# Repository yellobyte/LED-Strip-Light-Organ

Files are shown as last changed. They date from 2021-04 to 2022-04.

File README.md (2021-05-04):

# 3-Channel LED-Strip Light Organ with Arduino Nano #

A light (or color) organ is an electronic device which converts an audio signal into rhythmic light effects. Invented in the 70's they are still popular in discotheques and party rooms though.
Now that **LED Strips** became fairly cheap they can replace normal light bulbs used in the earlier years and make the color organ look more modern.

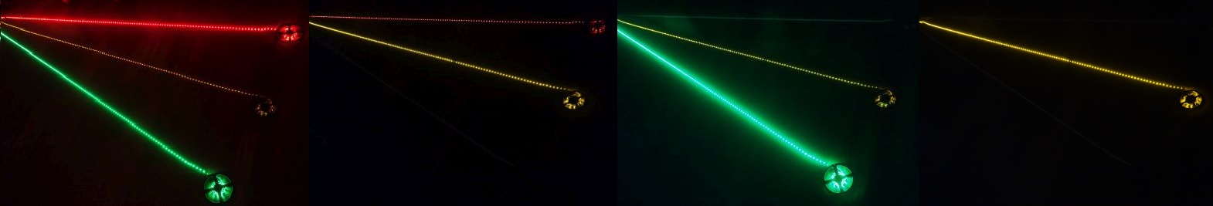
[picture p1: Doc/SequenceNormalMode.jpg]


The electronic circuit of a normal light organ separates the audio signal into several frequency bands and dimms the light bulbs or LEDs according to the average level of each band.

For a decent visual impression at least 3 bands (channels) are needed: low frequencies (bass), middle frequencies and high frequencies (treble). For best visual results each channel should control a light source of different color, e.g bass = red, middle = yellow and treble = green.

## Technical Infos ##

We have 3 channels and therefore control 3 LED Strips. Their specified working voltage must be 12V DC. The maximum length of the LED Strips the device can handle is mainly determined by the current consumption (amperes per meter length) of each LED Strip and the maximum current rating of the external 12V power supply used.

To give you a real world example: The external power supply I tested the device with was a MeanWell GS90A12 with a maximum current rating of 6.7A DC. Therefore I set the overcurrent limit to 2.2A per channel (the device itself doesn't need much). That limit allowed me to use LED Strips of 5m length with 60 LEDs (Type 3528 SMD in red, yellow or green) per meter. The overcurrent protection circuitry never got triggered.

The light organ has 3 working modes: [Normal](https://github.com/yellobyte/LED-Strip-Light-Organ/blob/main/Doc/NormalMode.mp4), [Rhythm](https://github.com/yellobyte/LED-Strip-Light-Organ/blob/main/Doc/RhythmMode.mp4) and [Cyclic](https://github.com/yellobyte/LED-Strip-Light-Organ/blob/main/Doc/Cyclic.mp4), which can be selected by pressing the **mode selection** button. 

An Arduino Nano 328P continuously samples all 3 filter outputs und transforms their voltage levels into digital PWM signals which feed the output stages with their IRF540N Power MOSFETs. Overtemperature & overcurrent protection (overload OL protection) has been integrated. 

The electrical circuit had to be devided into 2 separate [PCBs](https://github.com/yellobyte/LED-Strip-Light-Organ/blob/main/Doc/BoardTop.JPG), a **Filter-PCB** and a **Power-PCB** as I only call the basic version of the Eagle Design Tool my own and PCB size is limited to Eurocard size. But this proved to be very fortunate in the end for I redesigned the output stages a few times but didn't have to redo the analog stages. Please have a look at folder [**EagleFiles**](https://github.com/yellobyte/LED-Strip-Light-Organ/blob/main/EagleFiles) for schematic & PCB details.

The block diagram of the light organ is as follows:

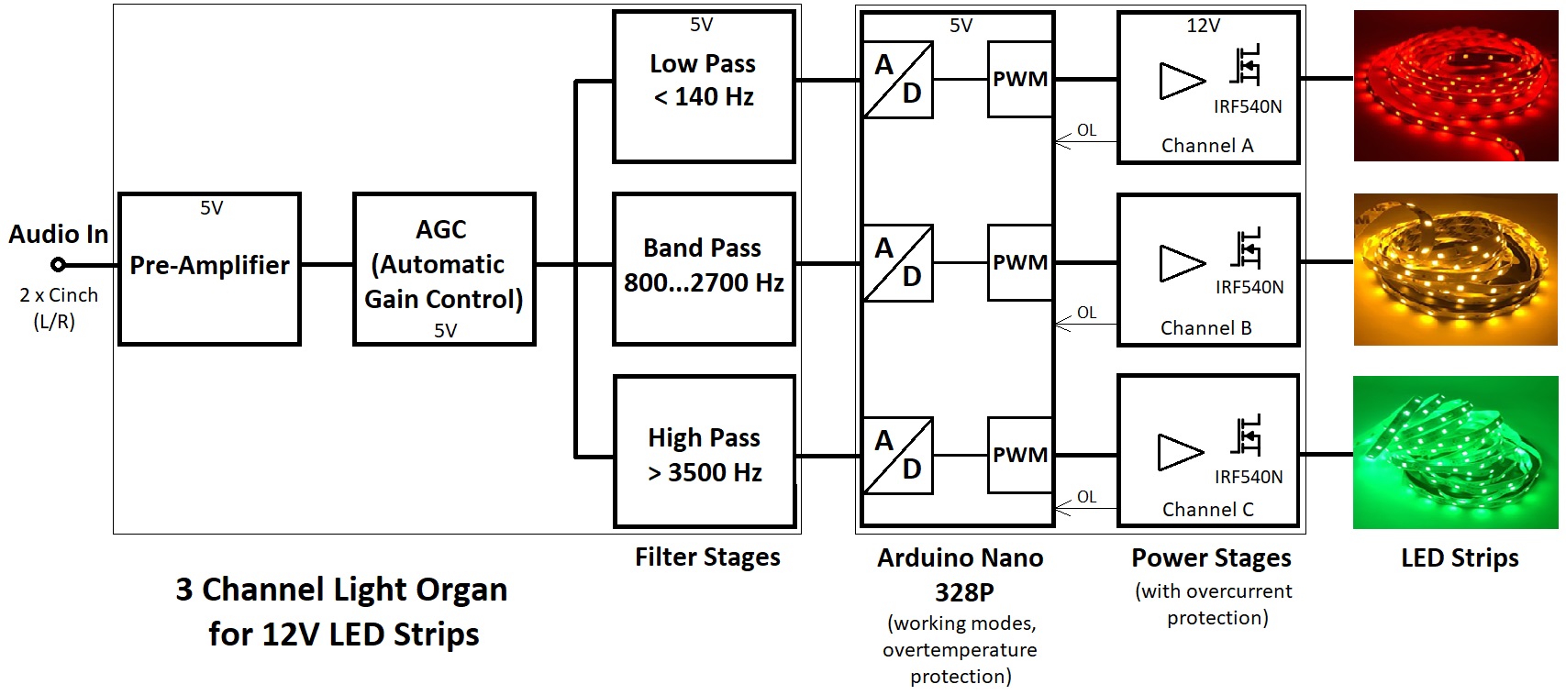
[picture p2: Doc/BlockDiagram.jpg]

   
### The Filter-PCB: ###

The MC33078 Op amps in the pre-amplifier and AGC stages proved perfect for the task. They might be substituted with cheaper Op amps, e.g. TL082, TLC277 or MC1458 but this comes with a loss of signal quality (distortion!). Especially the MC1458 wasn't able to pull the signal fully down to the lower rail and the TLC277 showed some crossover distortion.

The cheap LM358 Op amps used in the 3 filter stages generate crossover distortion as well but this is of no consequence in that particular application.

The AGC stage is simple but very effective and produces hardly any distortion even with high input signals applied. This stage is needed in order to normalize the signal level fed into the filter stages as the signal level from the many audio sources can vary by an order of magnitude (MP3/CD/Vinyl player, FM or internet radio, etc.).

Each of the 3 filter circuits uses an Op amp and some passive components (Rs/Cs). The resistors with strange values (6k16, 14k7, 16k9, 23k7, 71k5) belong to the E48 (2%) or E96 (1%) series. The filter circuits (2nd order) were calculated with the help of **FilterLab** from Microchip. It's available at no cost, easy to use and very intuitive. 

LED1 to LED6 have been added mainly for testing purposes. They come handy when you don't have any LED-Strips available but still want to do some tests on the device. They too are PWM controlled and show the exact same visual effects as the LED-Strips would.

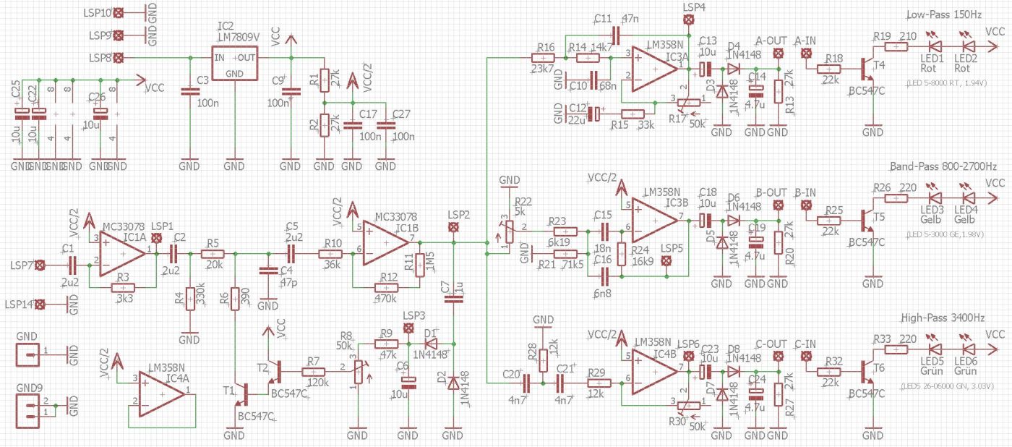
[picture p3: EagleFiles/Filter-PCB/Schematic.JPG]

     
### The Power-PCB: ###

The Arduino Nano 328P module is an ideal device for sampling the three filter outputs and generating PWM signals needed by the power stages. It only runs on 16MHz but this proved fast enough for the task.

The code running on the Arduino Nano is available in folder [Software](https://github.com/yellobyte/LED-Strip-Light-Organ/blob/main/Software). It was generated with VSCode/PlatformIO.

The Power MOSFETs IRF540N work as High-Side Switches (in "common drain" configuration) and need a gate voltage higher than the Nano can provide in this application, thats why 12V DC-DC converters (I/O isolated -> output side floating) had to be used. The reason is that the source voltage of the MOSFETs approaches the +12V supply voltage when switched on. To keep the MOSFETs turned on the IR2125 outputs must drive the MOSFETs gate voltage 10-12V higher than the supply voltage.

Shunt resistors (R6/R12/R18 - 0.15Ohm/2W/5%/Wire) sit between the MOSFETs and the output sockets in order to measure the output current and utilize the current sense input of the MOSFET drivers IR2125. When the IR2125 detects overcurrent it shuts down immediately until the next PWM impuls. The software in the Arduino Nano detects this condition and shuts down the affected channel even longer (5 sec) before releasing it again. No harm is done at all in case you have a permanent short on the output lines, provided you properly calibrated the trigger point of course!

The power stages by design could deliver 3-4 amperes per channel without problems. In practice the limiting factor probably will be the external 12V DC power supply. The driver MOSFETs IRF540N (Idmax > 20A) operate way from their absolute maximum ratings and only get handwarm in the enclosure (Model EXN-23361-SV from Bud Industries).

A temperature sensor LM35DZ connected to an Arduino Nano analog input pin is used to measure the temperature inside the enclosure. Temperatures over 50° celsius will shut down all channels and only temperatures below 40° celsius will release them. However, during my hour long tests the temperature overload never got triggered for the temperature inside the enclosure always hovered around 35-38° celsius.

JP1/JP2/JP3 are only needed for testing purposes, in normal working mode pins 1 & 2 should be shorted in order to allow the overload signal from the IR2125 ICs reach the Arduino Nano. R2/SV3 are only used for testing purposes as well.

Push button S1 is used for selecting the working mode.

The three TVS Diodes P6KE20A (D5/D9/D13) in parallel with the output sockets have a very fast response time and protect the device from possibly harmful voltage transients that might travel in from connected LED Strips. The latter act like big antennas when a few meters long!

D1 provides a very stable reference voltage needed by the A/D converters in the Arduino Nano.

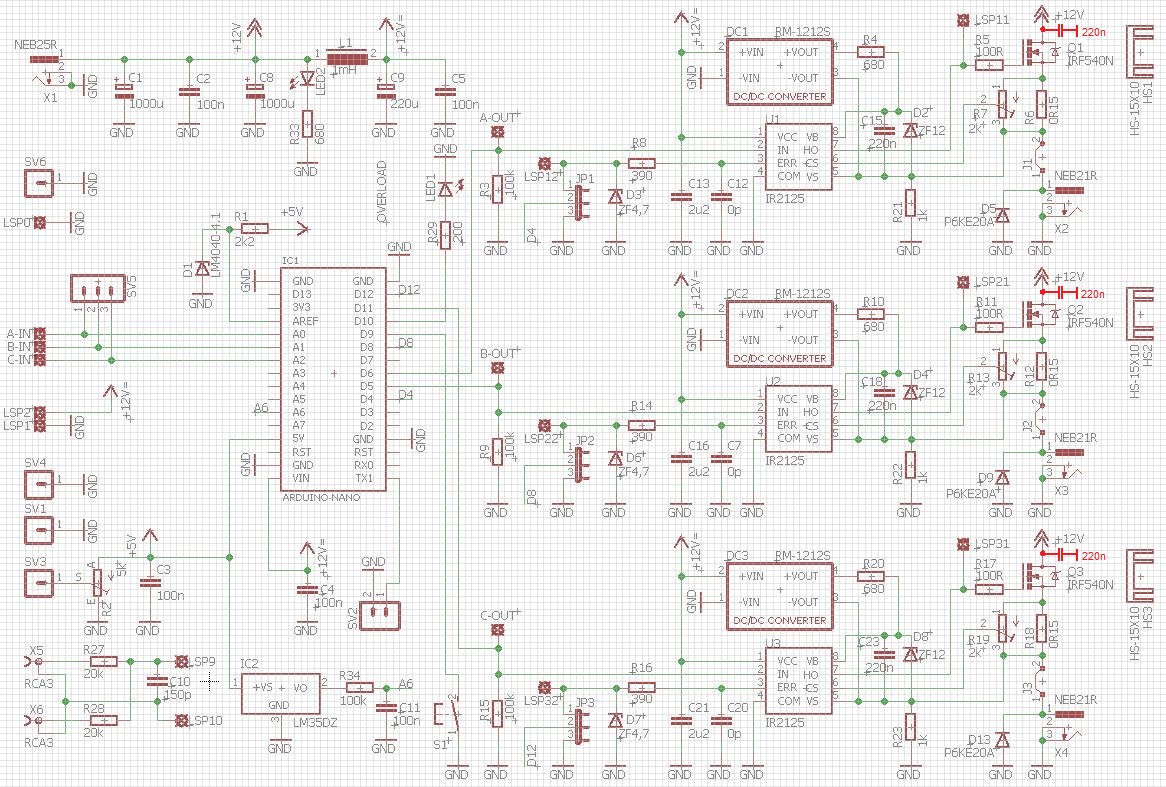
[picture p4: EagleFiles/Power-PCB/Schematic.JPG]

   
### The two [boards](https://github.com/yellobyte/LED-Strip-Light-Organ/blob/main/Doc/BoardTop.JPG) are connected as follows: ###

```c
 Filter-PCB ---  Power-PCB
      LSP7  ---  LSP9  (analog audio)
      LSP8  ---  LSP2  (+12V=)
      A-IN  ---  A-OUT (PWM channel A)
      B-IN  ---  B-OUT (PWM channel B)
      C-IN  ---  C-OUT (PWM channel C)
      A-OUT ---  A-IN  (filter output channel A)
      B-OUT ---  B-IN  (filter output channel B)
      C-OUT ---  C-IN  (filter output channel C)  
      GNDs  ---  GNDs   
```        

## How to calibrate the circuit ##

### Filter-PCB: ###
The pre-amplifier stage, the automatic gain control (AGC) stage and all three filter circuits have to be calibrated in order to produce optimal results. The procedure itself is fairly easy. Only obstacle is you need a function generator and ideally an oscilloscope. A cheap multimeter will do if you can´t get hold of such equipment but might spoil optimal performance of the device.

Necessary steps in correct order:

1) Adjust the trimpot R8 so that pins 1 & 2 of R8 are shorted (AGC is inactive that way). Apply a signal of 1kHz/0.5Vpp to X5 **or** X6 on the power board (one of the two Cinch/RCA sockets). It gets forwarded to LSP7 on the filter board (inverting input of pre-amplifier Op amp IC1A). 

2) Choose a value of R12 so that the signal level at LSP2 (output of Op amp IC1B) is close to 2.70Vpp. In my case I ended up with a R12 of 470k.

3) Increase the amplitude of the input signal to 2.0Vpp. Now adjust the trimpot R8 so that the signal level at LSP2 is close to 3.2Vpp.

At this point the pre-amplifier & AGC stages are properly calibrated. The filter stages follow:

4) Change the input signal to 50Hz/0.7Vpp and adjust R17 so that you get 3.6Vpp at LSP4.

5) Change the input signal to 1.3kHz/0.7Vpp and adjust R22 so that you get 3.6Vpp at LSP5.

6) Change the input signal to 6kHz/0.7Vpp and adjust R30 so that you get 3.6Vpp at LSP6.

That's it. The analog circuit on the **Filter-PCB** is now fully calibrated.

### Power-PCB: ###
Only the current limits of each channel (A/B/C) need to be calibrated. That's a bit tricky as you need a current running through the MOSFETs that has exactly the value you want the IR2125 to trigger. I used a cheap electronic load from Aliexpress (XY-FZ35) to accomplish that. 

Before you start make sure the Arduino Nano is REMOVED from the Power-PCB, your external power supply is NOT attached to the 12V power socket and there are NO jumpers on JP1/JP2/JP3 !

The following steps have to be done for each channel A/B/C, starting with channel A:

7) Adjust the trimpot R7 (R13/R19) so that U1 (U2/U3) pins 5 & 6 (CS & VS of IR2125) are shorted
8) Attach a voltmeter to LSP12 (LSP22/LSP32) and Ground
9) Attach the electronic load to the channel output socket (the socket for the LED-strip) and set the current limit to the desired trigger value 
10) Connect A-OUT (B/C-OUT) (IR2125 pin 2) with LSP2 (+12V=). That will switch the MOSFET on at the next step.
11) Now connect the external 12V power supply, the electronic load should see the programmed current flow
12) Slowly turn the screw on trimpot R7 (R13/R19) until the voltage on LSP12 (LSP22/LSP32) jumps from 0 to 4.7V. Stop turning immediately!
13) Remove the external 12V power supply and the electronic load 
14) Put the jumper back on pins 1 & 2 of JP1 (JP2/JP3) and remove the connection between LSP2 and A-OUT (B/C-OUT)
15) proceed with the next channel

Having all channels calibrated you can put the Arduino Nano back onto the board.
Those settings properly done for all channels, even a permanent short on the output sockets won't destroy your output stages.

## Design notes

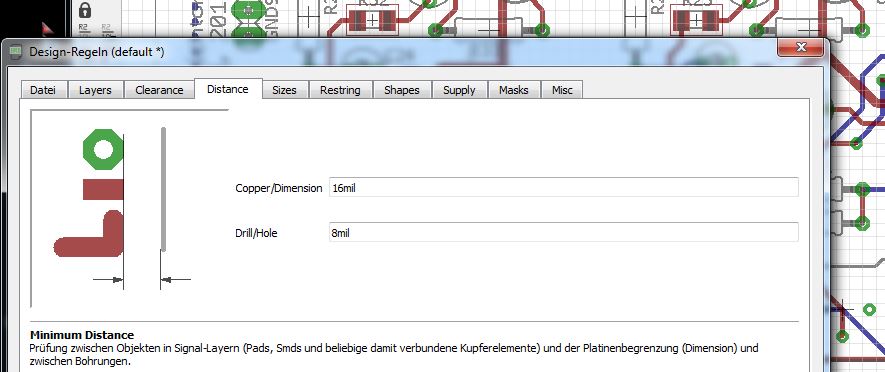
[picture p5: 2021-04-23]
EagleFiles/Filter-PCB/Design-Rules-Distance.JPG

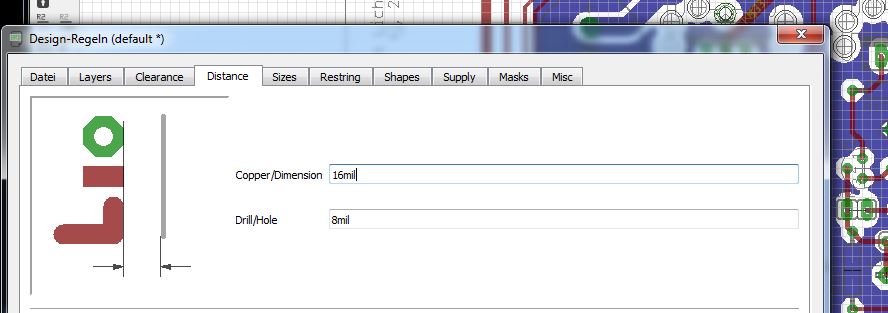
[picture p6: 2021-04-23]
EagleFiles/Power-PCB/Design-Rules-Distance.JPG

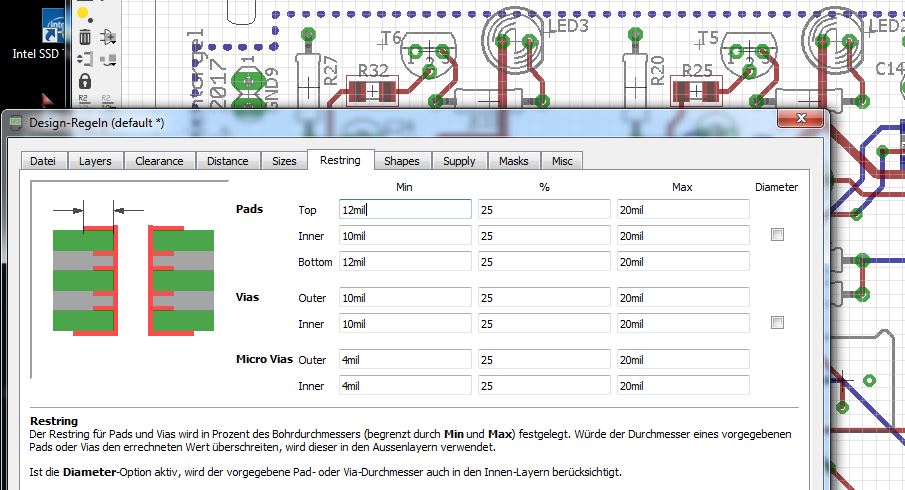
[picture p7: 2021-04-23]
EagleFiles/Filter-PCB/Design-Rules-Restring.JPG

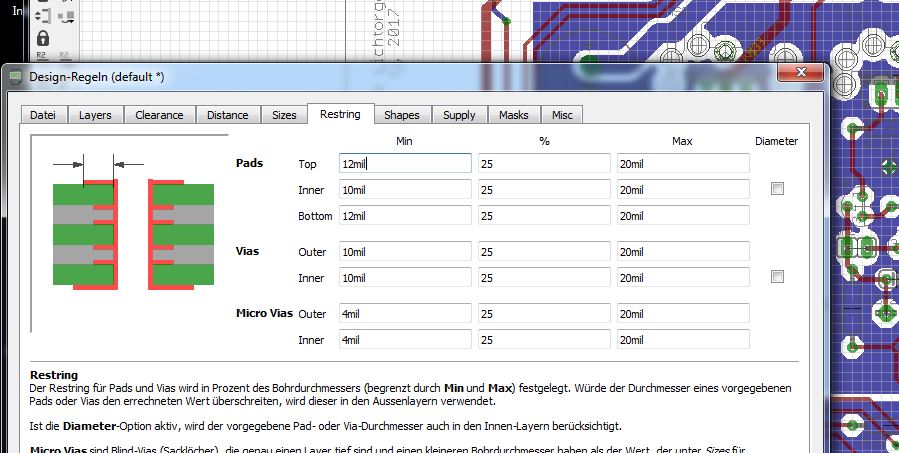
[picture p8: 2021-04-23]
EagleFiles/Power-PCB/Design-Rules-Restring.JPG

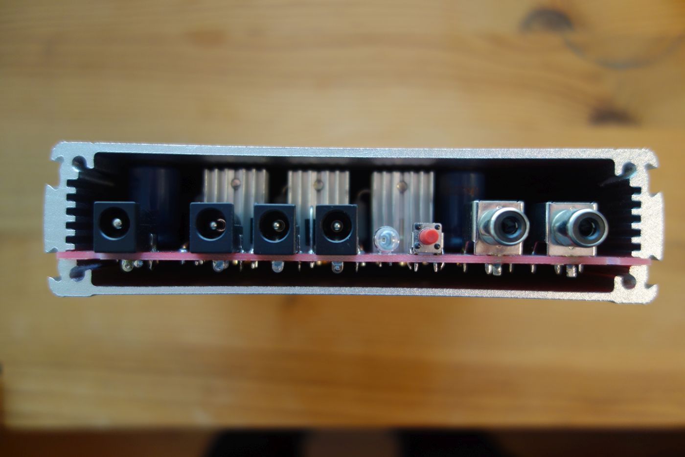
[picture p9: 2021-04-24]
Doc/RearOpen.JPG

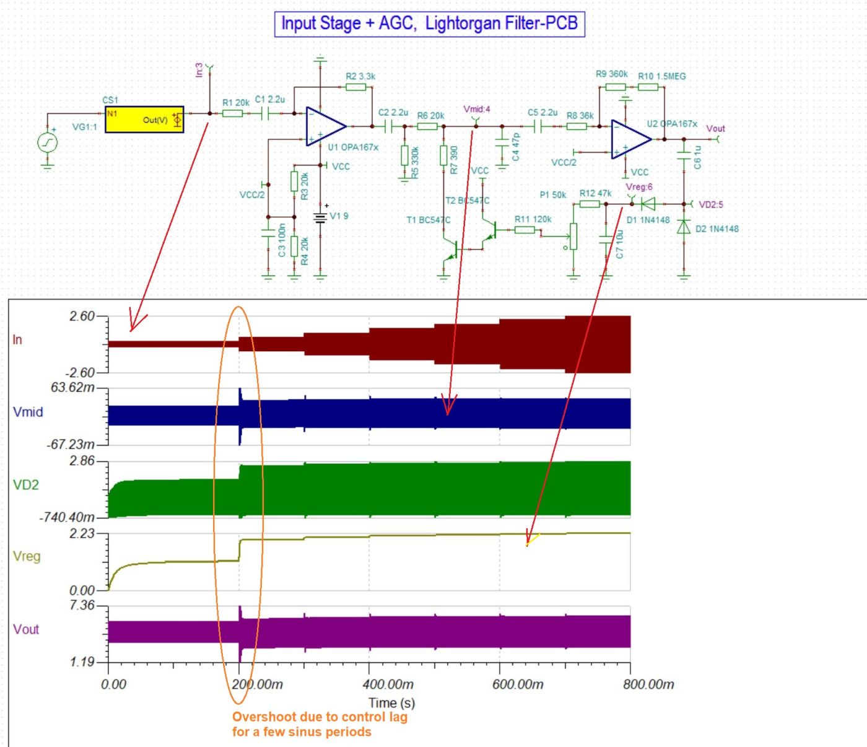
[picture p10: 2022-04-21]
Doc/SPICE Simulation of AGC Stage.JPG

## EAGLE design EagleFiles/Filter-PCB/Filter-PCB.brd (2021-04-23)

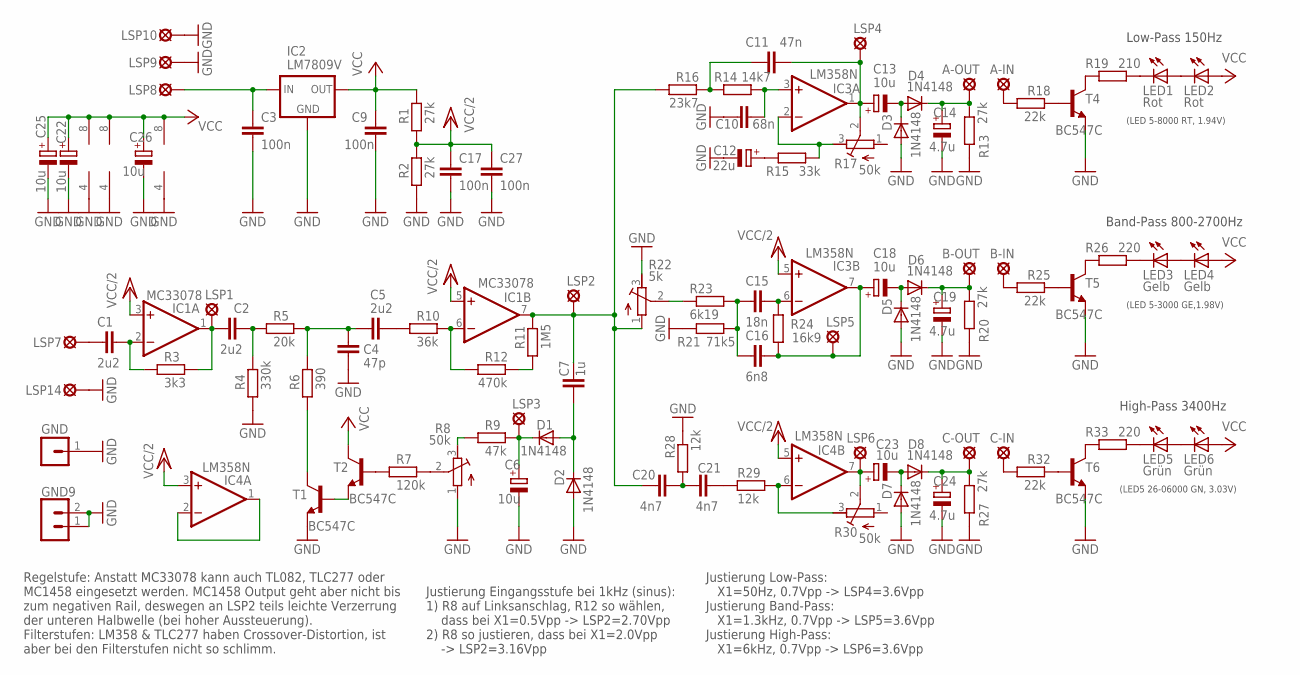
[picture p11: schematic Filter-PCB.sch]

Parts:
A-IN: LSP13
A-OUT: LSP13
B-IN: LSP13
B-OUT: LSP13
C1, C2, C5: 2u2; C1206
C3, C17: 100n; C050-024X044
C4: 47p; C1206
C6, C13, C18, C22, C23, C25, C26: 10u; TT2D4
C7: 1u; C050-024X044
C9, C27: 100n; C1206
C10: 68n; C1206
C11: 47n; C1206
C12: 22u; TT2D4
C14, C19, C24: 4.7u; TT2D4
C15: 18n; C1206
C16: 6n8; C1206
C20, C21: 4n7; C050-024X044
C-IN: LSP13
C-OUT: LSP13
D1, D2, D3, D4, D5, D6, D7, D8: 1N4148; SOD80C
GND: MA01-1
GND9: MA02-1
IC1: MC33078; DIL08
IC2: LM7809V; 78XXS
IC3, IC4: LM358N; DIL08
LED1, LED2: Rot; LED5MM
LED3, LED4: Gelb; LED5MM
LED5, LED6: Grün; LED5MM
LSP1, LSP2, LSP3, LSP4, LSP5, LSP6: LSP11
LSP7, LSP8, LSP9, LSP10, LSP14: LSP13
R1, R2: 27k; M1206
R3: 3k3; M1206
R4: 330k; M1206
R5: 20k; M1206
R6: 390; M1206
R7: 120k; M1206
R8, R17, R30: 50k; RTRIM64P
R9: 47k; M1206
R10: 36k; M1206
R11: 1M5; M1206
R12: 470k; 0207/10
R13, R20, R27: 27k; 0207/10
R14: 14k7; 0207/10
R15: 33k; M1206
R16: 23k7; 0207/10
R18, R25, R32: 22k; M1206
R19: 210; 0207/10
R21: 71k5; 0207/10
R22: 5k; RTRIM64P
R23: 6k19; 0207/10
R24: 16k9; 0207/10
R26, R33: 220; 0207/10
R28, R29: 12k; 0207/10
T1, T2, T4, T5, T6: BC547C; TO92

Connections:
GND: C3.2, C4.2, C6.-, C9.1, C10.1, C12.-, C14.-, C17.2, C19.-, C22.-, C24.-, C25.-, C26.-, C27.2, D2.A, D3.A, D5.A, D7.A, GND.1, GND9.1, GND9.2, IC1.4 (V-), IC2.GND, IC3.4 (V-), IC4.4 (V-), LSP9.MP, LSP10.MP, LSP14.MP, R2.1, R4.1, R8.1 (A), R13.1, R20.1, R21.1, R22.3 (E), R27.1, R28.2, T1.1 (E), T4.1 (E), T5.1 (E), T6.1 (E)
unnamed: R18.2, T4.2 (B)
unnamed: R25.2, T5.2 (B)
unnamed: R32.2, T6.2 (B)
unnamed: C1.2, IC1.2 (-IN), R3.1
unnamed: C2.2, R4.2, R5.1
unnamed: R6.1, T1.3 (C)
unnamed: C2.1, IC1.1 (OUT), LSP1.MP, R3.2
unnamed: C4.1, C5.1, R5.2, R6.2
unnamed: R7.1, T2.2 (B)
unnamed: R7.2, R8.2 (S)
unnamed: T1.2 (B), T2.1 (E)
unnamed: R8.3 (E), R9.1
unnamed: IC1.6 (-IN), R10.2, R12.1
unnamed: C7.1, C20.1, IC1.7 (OUT), LSP2.MP, R11.2, R16.1, R22.1 (A)
unnamed: C6.+, D1.C, LSP3.MP, R9.2
unnamed: C7.2, D1.A, D2.C
unnamed: C3.1, IC2.IN, LSP8.MP
unnamed: C11.1, R14.1, R16.2
unnamed: C5.2, R10.1
unnamed: R11.1, R12.2
unnamed: C10.2, IC3.3 (+IN), R14.2
unnamed: IC3.2 (-IN), R15.2, R17.3 (E)
unnamed: C11.2, C13.+, IC3.1 (OUT), LSP4.MP, R17.2 (S)
unnamed: C12.+, R15.1
unnamed: R22.2 (S), R23.1
unnamed: C13.-, D3.C, D4.A
unnamed: A-OUT.MP, C14.+, D4.C, R13.2
unnamed: C1.1, LSP7.MP
unnamed: R19.1, T4.3 (C)
unnamed: LED1.K (C), R19.2
unnamed: C24.+, C-OUT.MP, D8.C, R27.2
unnamed: C15.1, C16.1, R21.2, R23.2
unnamed: C15.2, IC3.6 (-IN), R24.2
unnamed: C21.2, R29.1
unnamed: C16.2, C18.+, IC3.7 (OUT), LSP5.MP, R24.1
unnamed: C20.2, C21.1, R28.1
unnamed: C18.-, D5.C, D6.A
unnamed: B-OUT.MP, C19.+, D6.C, R20.2
unnamed: A-IN.MP, R18.1
unnamed: R26.1, T5.3 (C)
unnamed: LED3.K (C), R26.2
unnamed: B-IN.MP, R25.1
unnamed: C23.+, IC4.7 (OUT), LSP6.MP, R30.2 (S)
unnamed: C-IN.MP, R32.1
unnamed: IC4.6 (-IN), R29.2, R30.3 (E)
unnamed: C23.-, D7.C, D8.A
unnamed: LED5.A, LED6.K (C)
unnamed: LED3.A, LED4.K (C)
unnamed: R33.1, T6.3 (C)
unnamed: LED5.K (C), R33.2
unnamed: LED1.A, LED2.K (C)
unnamed: IC4.1 (OUT), IC4.2 (-IN)
VCC: C9.2, C22.+, C25.+, C26.+, IC1.8 (V+), IC2.OUT, IC3.8 (V+), IC4.8 (V+), LED2.A, LED4.A, LED6.A, R1.2, T2.3 (C)
VCC/2: C17.1, C27.1, IC1.3 (+IN), IC1.5 (+IN), IC3.5 (+IN), IC4.3 (+IN), IC4.5 (+IN), R1.1, R2.2

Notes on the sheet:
Low-Pass 150Hz
Band-Pass 800-2700Hz
High-Pass 3400Hz
Justierung Eingangsstufe bei 1kHz (sinus): 1) R8 auf Linksanschlag, R12 so wählen, dass bei X1=0.5Vpp -> LSP2=2.70Vpp 2) R8 so justieren, dass bei X1=2.0Vpp -> LSP2=3.16Vpp
Justierung Low-Pass: X1=50Hz, 0.7Vpp -> LSP4=3.6Vpp Justierung Band-Pass: X1=1.3kHz, 0.7Vpp -> LSP5=3.6Vpp Justierung High-Pass: X1=6kHz, 0.7Vpp -> LSP6=3.6Vpp
Regelstufe: Anstatt MC33078 kann auch TL082, TLC277 oder MC1458 eingesetzt werden. MC1458 Output geht aber nicht bis zum negativen Rail, deswegen an LSP2 teils leichte Verzerrung der unteren Halbwelle (bei hoher Aussteuerung). Filterstufen: LM358 & TLC277 haben Crossover-Distortion, ist aber bei de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
(LED 5-8000 RT, 1.94V)
(LED 5-3000 GE,1.98V)
(LED5 26-06000 GN, 3.03V)

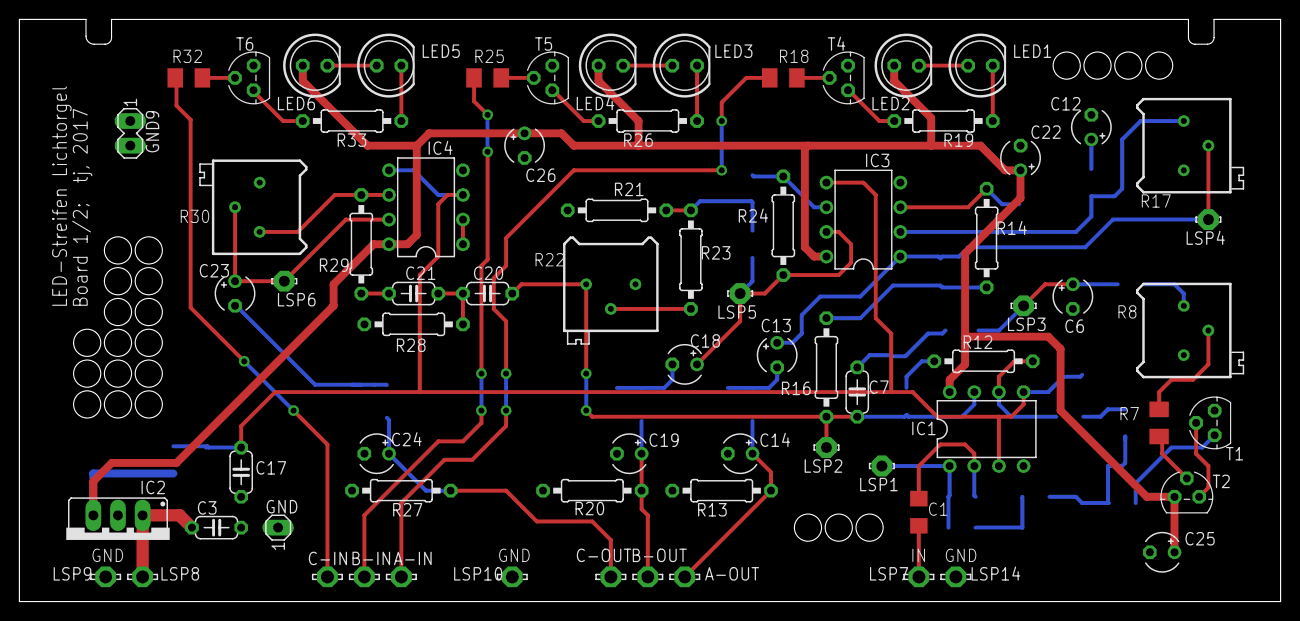
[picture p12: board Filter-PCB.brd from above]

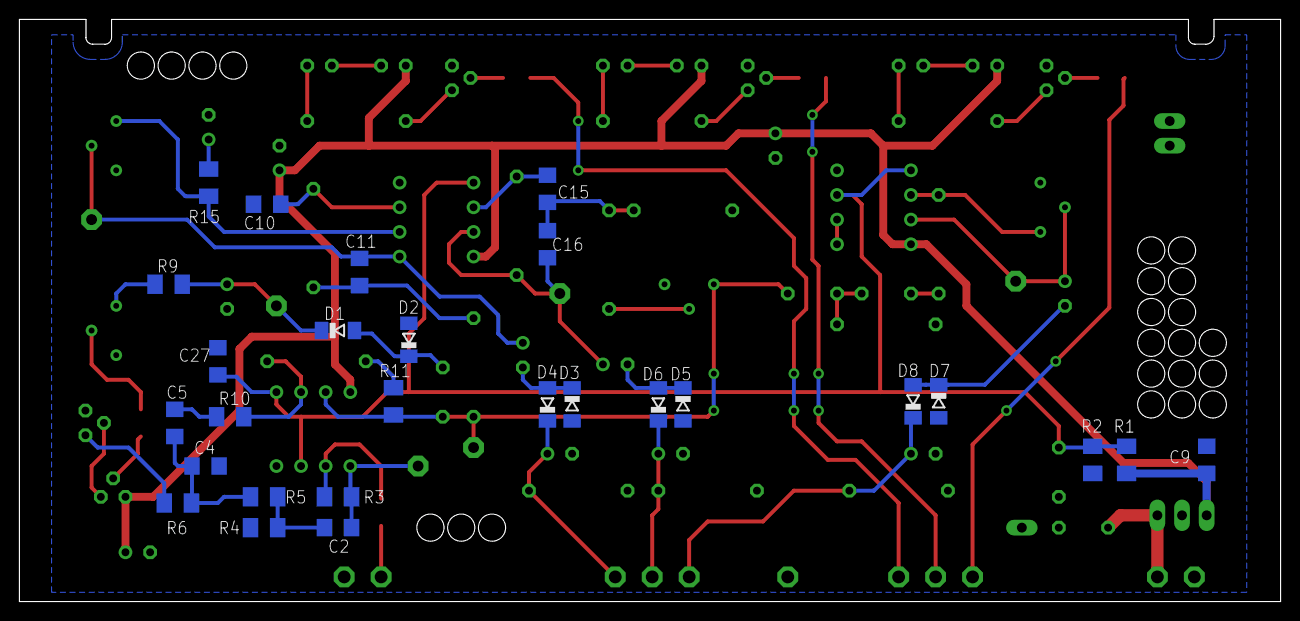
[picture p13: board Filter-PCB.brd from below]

Board: 2 copper layers, 130.0 x 60.0 mm, 100 parts (27 on the bottom side), 55 nets.

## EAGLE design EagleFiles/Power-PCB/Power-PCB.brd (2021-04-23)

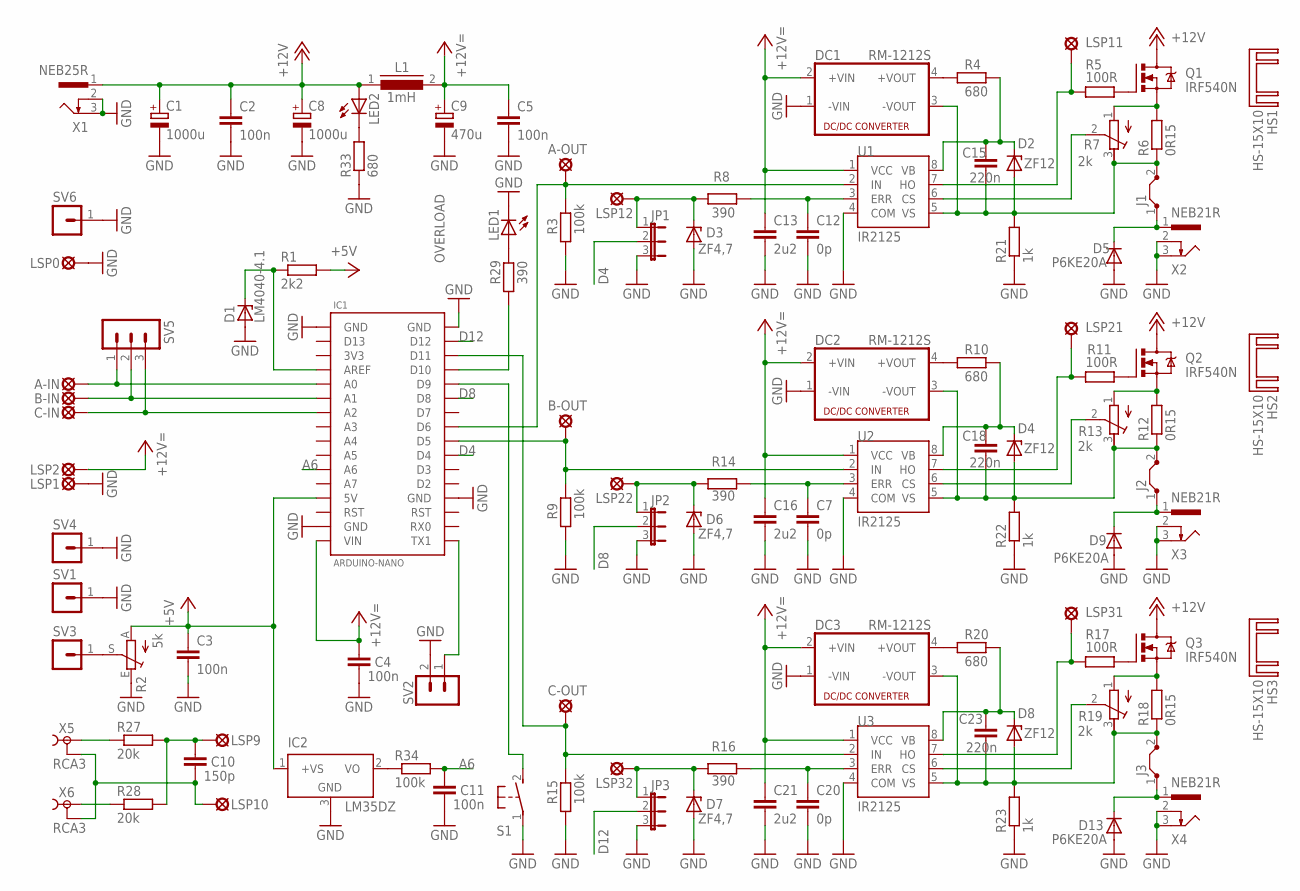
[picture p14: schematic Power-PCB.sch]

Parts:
A-IN: LSP13
A-OUT: LSP13
B-IN: LSP13
B-OUT: LSP13
C1, C8: 1000u; E5-13
C2, C3, C4, C5, C11: 100n; C050-024X044
C7, C12, C20: 0p; C025-024X044
C9: 470u; E5-10,5
C10: 150p; C025-024X044
C13, C16, C21: 2u2; C1206
C15, C18, C23: 220n; C050-024X044
C-IN: LSP13
C-OUT: LSP13
D1: LM4040-4.1; TO-92
D2, D4, D8: ZF12; DO34Z7
D3, D6, D7: ZF4,7; DO34Z7
D5, D9, D13: P6KE20A; C1702-05
DC1, DC2, DC3: RM-1212S; NME
HS1, HS2, HS3: HS-15X10; HEATSINK-TO220-15X10X21
IC1: ARDUINO-NANO
IC2: LM35DZ; TO92
J1, J2, J3: JUMPER-BRIGDE12MM; 12-THICK-WIRE
JP1, JP2, JP3: JP2E; JP2
L1: 1mH; L-09HCP
LED1: LED5MM
LED2: LED3MM
LSP0, LSP1, LSP2, LSP9, LSP10: LSP13
LSP11, LSP12, LSP21, LSP22, LSP31, LSP32: LSP11
Q1, Q2, Q3: IRF540N; TO220BV
R1: 2k2; M1206
R2: 5k; PT-10
R3, R9, R15: 100k; 0207/10
R4, R10, R20: 680; 0207/10
R5, R11, R17: 100R; M1206
R6, R12, R18: 0R15; 0617V
R7, R13, R19: 2k; RTRIM64W
R8, R14, R16: 390; M1206
R21, R22, R23: 1k; 0207/2V
R27, R28: 20k; M1206
R29: 390; 0207/10
R33: 680; M1206
R34: 100k; M1206
S1: 31-XX; B3F-31XX
SV1, SV3, SV4, SV6: MA01-1
SV2: MA02-1
SV5: MA03-1
U1, U2, U3: IR2125; DIL08
X1: NEB25R; NEB21R
X2, X3, X4: NEB21R
X5, X6: RCA3

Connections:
3V3: IC1.3V3
+5V: C3.1, IC1.+5V (5V), IC2.1 (+VS), R1.2, R2.A
+12V: C1.+, C2.1, C8.+, L1.1, LED2.A, Q1.D, Q2.D, Q3.D, X1.1
+12V=: C4.1, C5.1, C9.+, C13.1, C16.1, C21.1, DC1.2 (+VIN), DC2.2 (+VIN), DC3.2 (+VIN), IC1.VIN, L1.2, LSP2.MP, U1.1 (VCC), U2.1 (VCC), U3.1 (VCC)
A6: C11.1, IC1.A6, R34.2
AREF: D1.2 (C), IC1.AREF, R1.1
D4: IC1.D4, JP1.2
D5: B-OUT.MP, IC1.D5, R9.2, U2.2 (IN)
D6: A-OUT.MP, IC1.D6, R3.2, U1.2 (IN)
D8: IC1.D8, JP2.2
D11: C-OUT.MP, IC1.D11, R15.2, U3.2 (IN)
D12: IC1.D12, JP3.2
GND: C1.-, C2.2, C3.2, C4.2, C5.2, C7.2, C8.-, C9.-, C11.2, C12.2, C13.2, C16.2, C20.2, C21.2, D1.3 (A), D3.A, D5.A, D6.A, D7.A, D9.A, D13.A, DC1.1 (-VIN), DC2.1 (-VIN), DC3.1 (-VIN), IC1.GND, IC1.GND1 (GND), IC1.GND2 (GND), IC1.GND3 (GND), IC2.3 (GND), JP1.3, JP2.3, JP3.3, LED1.K (C), LSP0.MP, LSP1.MP, R2.E, R3.1, R9.1, R15.1, R21.1, R22.1, R23.1, R33.1, S1.1, SV1.1, SV2.2, SV4.1, SV6.1, U1.4 (COM), U2.4 (COM), U3.4 (COM), X1.2, X1.3, X2.2, X2.3, X3.2, X3.3, X4.2, X4.3
unnamed: LED1.A, R29.2
unnamed: A-IN.MP, IC1.A0, SV5.1
unnamed: B-IN.MP, IC1.A1, SV5.2
unnamed: C-IN.MP, IC1.A2, SV5.3
unnamed: C12.1, R8.1, U1.3 (ERR)
unnamed: IC1.TX1, SV2.1
unnamed: IC2.2 (VO), R34.1
unnamed: DC1.4 (+VOUT), R4.1
unnamed: D5.C, J1.1, X2.1
unnamed: C7.1, R14.1, U2.3 (ERR)
unnamed: DC2.4 (+VOUT), R10.1
unnamed: R7.2 (S), U1.6 (CS)
unnamed: C20.1, R16.1, U3.3 (ERR)
unnamed: LED2.K (C), R33.2
unnamed: DC3.4 (+VOUT), R20.1
unnamed: Q1.G, R5.2
unnamed: Q1.S, R6.2, R7.1 (A)
unnamed: Q2.S, R12.2, R13.1 (A)
unnamed: Q3.S, R18.2, R19.1 (A)
unnamed: LSP11.MP, R5.1, U1.7 (HO)
unnamed: D6.C, JP2.1, LSP22.MP, R14.2
unnamed: Q2.G, R11.2
unnamed: LSP21.MP, R11.1, U2.7 (HO)
unnamed: R13.2 (S), U2.6 (CS)
unnamed: D9.C, J2.1, X3.1
unnamed: R2.S, SV3.1
unnamed: Q3.G, R17.2
unnamed: LSP31.MP, R17.1, U3.7 (HO)
unnamed: R19.2 (S), U3.6 (CS)
unnamed: D13.C, J3.1, X4.1
unnamed: D3.C, JP1.1, LSP12.MP, R8.2
unnamed: D7.C, JP3.1, LSP32.MP, R16.2
unnamed: R27.1, X5.1
unnamed: R28.1, X6.1
unnamed: C10.2, LSP10.MP, X5.2, X5.2@1 (2), X5.2@2 (2), X6.2, X6.2@1 (2), X6.2@2 (2)
unnamed: C10.1, LSP9.MP, R27.2, R28.2
unnamed: IC1.D9, S1.2 (S)
OVERLOAD: IC1.D10, R29.1
VBU1: C15.1, D2.C, R4.2, U1.8 (VB)
VBU2: C18.1, D4.C, R10.2, U2.8 (VB)
VBU3: C23.1, D8.C, R20.2, U3.8 (VB)
VSU1: C15.2, D2.A, DC1.3 (-VOUT), J1.2, R6.1, R7.3 (E), R21.2, U1.5 (VS)
VSU2: C18.2, D4.A, DC2.3 (-VOUT), J2.2, R12.1, R13.3 (E), R22.2, U2.5 (VS)
VSU3: C23.2, D8.A, DC3.3 (-VOUT), J3.2, R18.1, R19.3 (E), R23.2, U3.5 (VS)

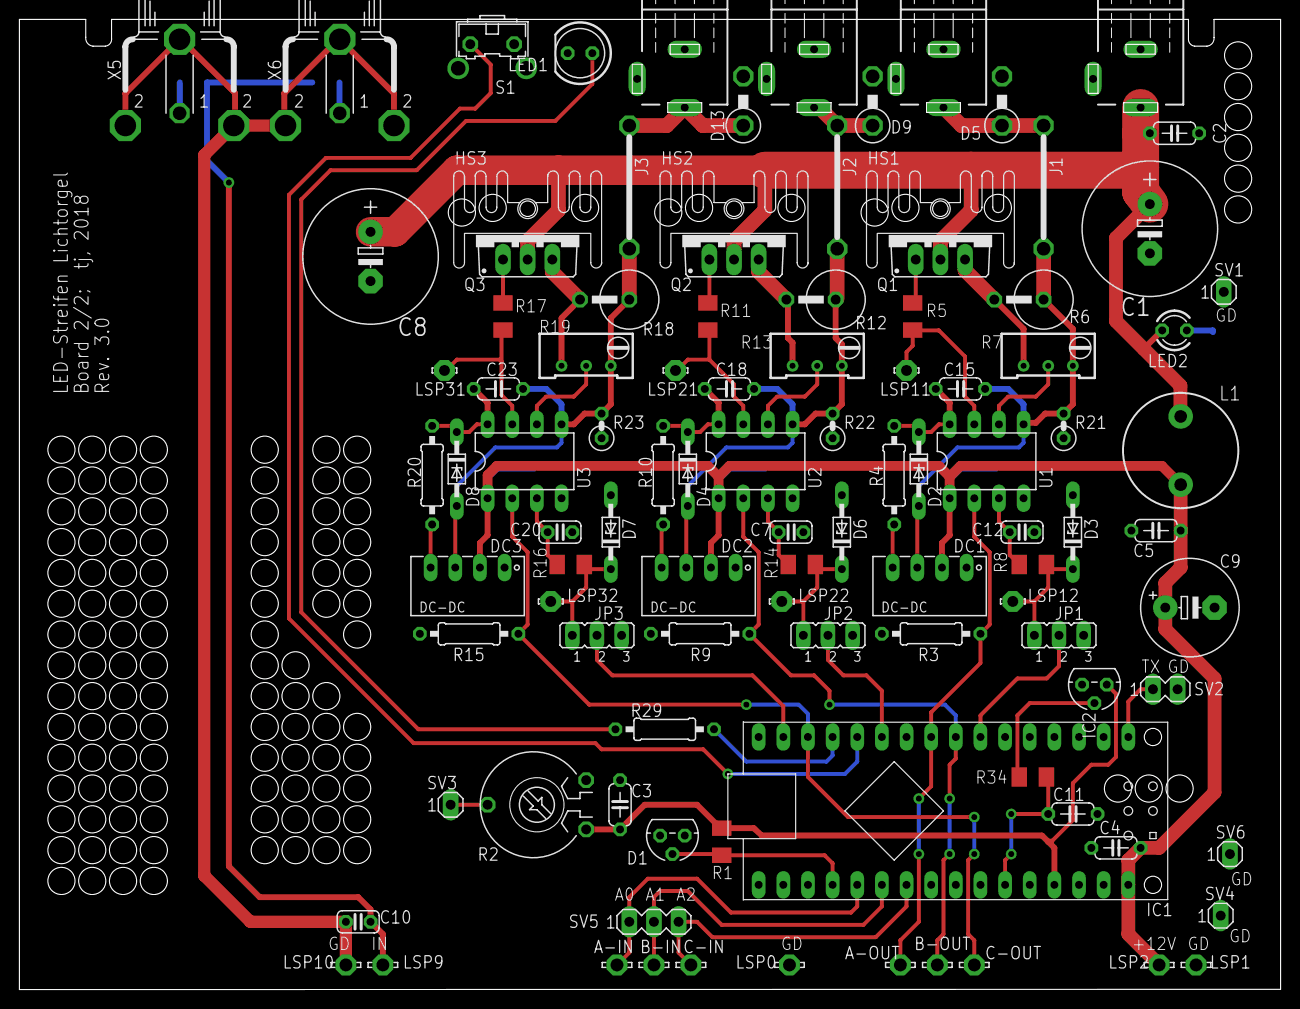
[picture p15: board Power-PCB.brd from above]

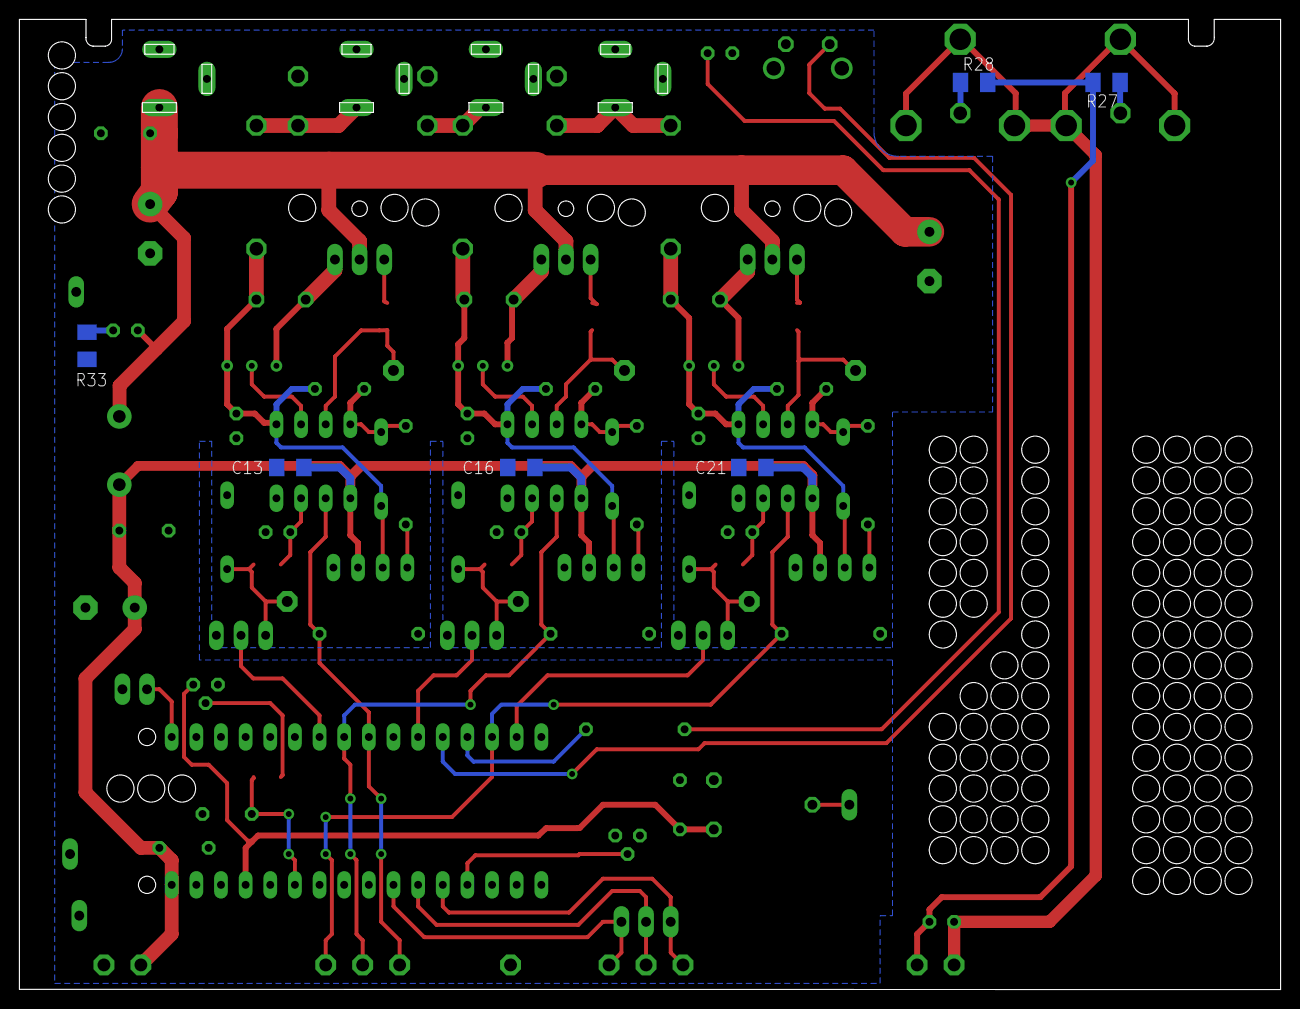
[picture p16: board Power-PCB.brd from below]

Board: 2 copper layers, 130.0 x 100.0 mm, 109 parts (6 on the bottom side), 56 nets.

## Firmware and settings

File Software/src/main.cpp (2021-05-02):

/*
 * LED-Strip Light Organ with 3 channels
 *
 * Bass:  level at ADC0 (PC0, Arduino Nano: A0) determines PWM value at OC0A (PD6, Arduino Nano: D6),
 *        associated overload signal at PD4 (PCINT20, Arduino Nano: D4)
 * Middle: level at ADC1 (PC1, Arduino Nano: A1) determines PWM value at OC0B (PD5, Arduino Nano: D5)
 *         associated overload signal at PB0 (PCINT0, Arduino Nano: D8)
 * Treble: level at ADC2 (PC2, Arduino Nano: A2) determines PWM value at OC2A (PB3, Arduino Nano: D11)
 *         associated overload signal at PB4 (PCINT4, Arduino Nano: D12)
 * Overload: LED at PB2 (Arduino Nano: D10)
 *           A single channel stays off for 5 sec after detecting a current overload.
 *           After detecting thermal overload (ca. 50° celsius) ALL channels stay off until temperature
 *           drops below 40° celsius or after reboot when temp < 50 deg.
 * Temperature control: LM35 delivers 0mV + 10mV per deg celsius at ADC6 (Arduino Nano: A6). 
 * Mode Switch: connected to PB1 (Arduino Nano: D9) for selecting operation mode.
 *
 * Created: 07.07.2017
 * Author : Thomas Jentzsch (yellobyte@bluewin.ch)
 */ 

#include <Arduino.h>

#define NUM_WORKING_MODES 3
#define NUM_CHANNELS      3
#define OL_TIMER_VALUE    5000          // 5s
#define TIMER_TEMPERATURE 10000         // 10s
#define ADC_REF_EXT       0
#define ADC_REF_VCC       1

volatile uint8_t overload;              // overload marker: Bit 7 for temp & Bit 2-0 for channels
volatile uint8_t overloadMessage;       // overload message to be printed
volatile uint8_t blinkStatus;           // overload LED status
volatile uint16_t timer[NUM_CHANNELS];  // timer per channel (for overload handling)
volatile uint16_t timerTemperature;     // timer for checking temp
volatile uint16_t timerMode;            // timer used in misc modes
volatile uint8_t timerBlink;
uint8_t workingMode;                    // 0 = normal light organ, 1 = bass rhythm, 2 = cyclic 

uint8_t valueOld[NUM_CHANNELS], 
        pwm, valueNew = 0, 
        i = 0, ii = 0;
uint16_t adc = 0;

// 50% PWM on an LED actually does not mean 50% brightness (it's probably more 75%), therefore we need some 
// kind of translation table for PWM -> brightness. Quite a lot of testing was required on that issue.
// strongly exponential:
/* uint8_t myExp[256] = { 0, 1, 1, 1, 1, 1, 1, 1, 1, 1, 1, 1, 1, 1, 1, 1,                   // 0-15
            1, 1, 1, 1, 1, 1, 1, 1, 1, 1, 1, 1, 1, 2, 2, 2,                                 // 16-31
            2, 2, 2, 2, 2, 2, 2, 2, 2, 2, 2, 2, 2, 2, 3, 3,                                 // 32-47
            3, 3, 3, 3, 3, 3, 3, 3, 4, 4, 4, 4, 4, 4, 4, 5,                                 // 48-63
            5, 5, 5, 5, 5, 6, 6, 6, 6, 6, 6, 7, 7, 7, 7, 7,                                 // 64-79
            8, 8, 8, 8, 9, 9, 9, 10, 10, 10, 11, 11, 11, 12, 12, 13,                        // 80-95
            13, 14, 14, 14, 15, 15, 16, 16, 17, 17, 18, 18, 19, 19, 20, 21,                 // 96-111
            21, 22, 22, 23, 24, 24, 25, 25, 26, 27, 27, 28, 29, 30, 30, 31,                 // 112-127
            32, 33, 33, 34, 35, 36, 37, 37, 38, 39, 40, 41, 42, 43, 44, 44,                 // 128-143
            45, 46, 47, 48, 49, 50, 51, 52, 54, 55, 56, 57, 58, 59, 60, 61,                 // 144-159
            62, 64, 65, 66, 67, 69, 70, 71, 72, 74, 75, 76, 78, 79, 81, 82,                 // 160-175
            83, 85, 86, 88, 89, 91, 92, 94, 95, 97, 98, 100, 102, 103, 105, 107,            // 176-191
            108, 110, 112, 114, 115, 117, 119, 121, 123, 124, 126, 128, 130, 132, 134, 136, // 192-207
            138, 140, 142, 144, 146, 148, 150, 152, 154, 157, 159, 161, 163, 165, 168, 170, // 208-223
            172, 175, 177, 179, 182, 184, 187, 189, 192, 194, 197, 199, 202, 204, 207, 209, // 224-239
            212, 215, 217, 220, 223, 226, 228, 231, 234, 237, 240, 243, 246, 249, 252, 255  // 240-255
};*/

// somewhat exponential - makes a good visual impression
uint8_t myExp[256] = { 0, 1, 1, 1, 1, 1, 1, 1, 1, 1, 1, 1, 1, 1, 1, 1,
            1, 2, 2, 2, 2, 2, 2, 2, 2, 2, 3, 3, 3, 3, 3, 3,
            4, 4, 4, 4, 5, 5, 5, 5, 6, 6, 6, 7, 7, 7, 8, 8,
            9, 9, 9, 10, 10, 11, 11, 11, 12, 12, 13, 13, 14, 14, 15, 15,
            16, 16, 17, 17, 18, 18, 19, 19, 20, 20, 21, 22, 22, 23, 23, 24,
            25, 25, 26, 27, 27, 28, 29, 29, 30, 31, 31, 32, 33, 33, 34, 35,
            36, 36, 37, 38, 39, 40, 40, 41, 42, 43, 44, 44, 45, 46, 47, 48,
            49, 50, 50, 51, 52, 53, 54, 55, 56, 57, 58, 59, 60, 61, 62, 63,
            64, 65, 66, 67, 68, 69, 70, 71, 72, 73, 74, 75, 76, 77, 79, 80,
            81, 82, 83, 84, 85, 87, 88, 89, 90, 91, 93, 94, 95, 96, 97, 99,
            100, 101, 102, 104, 105, 106, 108, 109, 110, 112, 113, 114, 116, 117, 118, 120,
            121, 122, 124, 125, 127, 128, 129, 131, 132, 134, 135, 137, 138, 140, 141, 143,
            144, 146, 147, 149, 150, 152, 153, 155, 156, 158, 160, 161, 163, 164, 166, 168,
            169, 171, 172, 174, 176, 177, 179, 181, 182, 184, 186, 188, 189, 191, 193, 195,
            196, 198, 200, 202, 203, 205, 207, 209, 211, 212, 214, 216, 218, 220, 222, 224,
            225, 227, 229, 231, 233, 235, 237, 239, 241, 243, 245, 247, 249, 251, 253, 255
};

/* alternatives, abandoned in favor of fixed array
uint8_t myExp(float in) {
  float pwmf = (float) (in / 255);
  //pwmf = pwmf * pwmf  pwmf;
  pwmf = pwmf * pwmf;
  return pwmf * 255;
}
*/

void ADCInit(uint8_t reference) {
	
  if (reference == ADC_REF_EXT) {
    ADMUX &= ~((1<<REFS1)|(1<<REFS0));  // Use external reference
  }
  else {
    ADMUX |= (1<<REFS0);                // Set reference to AVcc
    ADMUX &= ~(1<<REFS1);
  }
  ADCSRA |= (1<<ADEN)|                        // Enable ADC
            (1<<ADPS2)|(1<<ADPS1)|(1<<ADPS0); // Set prescaler to 128
                                              // Fadc=Fcpu/prescaler=16000000/128=125kHz
                                              // Fadc should be between 50kHz and 200kHz
  // in case interrupt routine is used
  /*										
  ADCSRA |= (1<<ADIE)|                  // interrupt enabled
            (1<<ADFR) or (1<<ADATE);    // for free running (depending on chip)
  ADCSRA |= (1<<ADSC);                  // Start first conversion
  */
}

uint16_t ADCRead(uint8_t channel) {

#if defined(__AVR_ATmega168__) || defined(__AVR_ATmega168P__) || defined(__AVR_ATmega328__) || defined(__AVR_ATmega328P__)
  if (channel > 7) return 0;
#else	
  if (channel > 5) return 0;
#endif
  ADMUX &= ~((1<<MUX2)|(1<<MUX1)|(1<<MUX0));
  ADMUX |= (channel & 0x07);
  ADCSRA |= (1<<ADSC);                // start Single conversion
  while (!(ADCSRA & (1<<ADIF)));      // wait for conversion to complete
  ADCSRA |=(1<<ADIF);                 // clear ADIF by writing one to it
	
  return (ADC);
}

/*
// Interrupt routine for ADC conversion complete, not used
ISR(ADC_vect)
{
  ...
  erg = ADC; 
  ...
}
*/

// helper function
long map(long x, long in_min, long in_max, long out_min, long out_max)
{
  return (x - in_min) * (out_max - out_min) / (in_max - in_min) + out_min;
}

// checking switch for mode selection, returns 1 when falling edge on PB1 detected
uint8_t switchCheck(void)
{
  static uint8_t  portBuffer, 
                  oldStatus = 1;  // switch not pressed
  uint8_t ret = 0;
  uint8_t counter;

  if ((PINB & (1<<PB1)) != (portBuffer & (1<<PB1))) {
    // switch status has changed
    for ( counter=0 ; counter<6 ; ) {
      portBuffer = PINB;
      _delay_us(150);
      if( (PINB & (1<<PB1)) == (portBuffer & (1<<PB1)) )
        counter++;    // stable
      else
        counter = 0;  // not stable yet
    }
    // stable for 6 * 150us = 900us
    if (oldStatus && !(portBuffer & (1<<PB1))) {  // falling edge ?
      ret = 1;
    }
    oldStatus = (portBuffer & (1<<PB1)) ? 1 : 0;  // remember last stable level
  }

  return(ret);
}

ISR(PCINT0_vect)
{
  if ((PINB & (1<<PB0)) != 0)
  {
    // LOW to HIGH at PB0 (Arduino Nano: D8, overload signal channel B)
    OCR0B = 0;                    // channel B: instant PWM off
    overload |= (1<<1);
    if (timer[1] == 0) {          // new overload only when old expired
      timer[1] = OL_TIMER_VALUE;  // otherwise IR2125 will trigger a message each PWM signal
      overloadMessage |= (1<<1);  // trigger message
    }
  }
  if ((PINB & (1<<PB4)) != 0)
  {
    // LOW to HIGH at PB4 (Arduino Nano: D12, overload signal channel C)
    OCR2A = 0;                    // channel C: instant PWM off
    overload |= (1<<2);
    if (timer[2] == 0) {          // new overload only when old expired
      timer[2] = OL_TIMER_VALUE;  // otherwise IR2125 will trigger a message each PWM signal
      overloadMessage |= (1<<2);  // trigger message	
    }
  }
}

ISR(PCINT2_vect)
{
  if ((PIND & (1<<PD4)) != 0)
  {
    // LOW to HIGH at PD4 (Arduino Nano: D4, overload signal channel A)
    OCR0A = 0;                    // channel A: instant PWM off
    overload |= (1<<0);
    if (timer[0] == 0) {          // new overload only when old expired
      timer[0] = OL_TIMER_VALUE;  // otherwise IR2125 will trigger a message each PWM signal
      overloadMessage |= (1<<0);  // trigger message	
    }
  }
}

//ISR(TIMER1_OVF_vect){
ISR(TIMER1_COMPA_vect){
  if (timer[0]) --timer[0];
  if (timer[1]) --timer[1];
  if (timer[2]) --timer[2];
  if (timerTemperature) --timerTemperature;
  if (timerMode) --timerMode;
  if (timerBlink) --timerBlink;
}

void setup() {
  // put your setup code here, to run once:
  Serial.begin(38400);

  overload = overloadMessage = 0;
  timerTemperature = TIMER_TEMPERATURE;
  timerMode = timerBlink = 0;
  workingMode = 0;
  for ( i=0; i<NUM_CHANNELS; i++) {
    valueOld[i] = 0;	
  }
	
  // port settings
  DDRD = ((1<<PD6) | (1<<PD5));           // PD6(D6) & PD5(D5) PWM output (OC0A & OC0B)
  DDRB = ((1<<PB3) | (1<<PB2));           // PB3(D11) PWM output (OC2A) & PB2(D10) output overload LED
  PORTB |= (1<<PB1);                      // activate pull-up for switch at PB1 (D9)
  PORTB &= ~(1<<PB2);                     // overload LED at PB2 (D10) off
	
  // initialize timer 0 (Ch A+B) & timer 2 (Ch C) for PWM
  OCR0A = OCR0B = OCR2A = 0;

  TCCR0A = (1<<WGM00);                    // phase correct PWM mode (mode 1) for timer 0 (Ch A+B)
  TCCR0A |= ((1<<COM0A1) | (1<<COM0B1));  // none inverting mode for OC0A & OC0B
  TCCR0B |= ((1<<CS01) | (1<<CS00));      // prescaler to 64 (phase correct PWM: 490Hz) & start PWM

  TCCR2A = (1<<WGM20);                    // phase correct PWM mode (mode 1) for timer 2 (Ch C)
  TCCR2A |= (1<<COM2A1);                  // none inverting mode for OC2A
  TCCR2B |= (1<<CS22);                    // prescaler to 64 (phase correct PWM: 490Hz) & start PWM

  // init timer 1
  //TCCR1B = (1<<CS11) | (1<<CS10);       // prescaler to 64 (top = 0xFFFF -> overflow irq every 0.26s)
  //TIMSK1 |= (1<<TOIE1);                 // timer 1 overflow interrupt enabled
  TCCR1B = ((1<<WGM12) | (1<<CS11) | (1<<CS10)); // prescaler to 64, CTC Mode 4 (OCR1A = TOP)
  OCR1A = 249;                            // 249: timer 1 interrupt every ms
  TIMSK1 |= (1<<OCIE1A);                  // timer 1 OC1A interrupt enabled

  // enabling pin change interrupts
  PCICR |= (1<<PCIE2) | (1<<PCIE0);					
  PCMSK2 |= (1<<PCINT20);                 // PD4 (PCINT20) overload at channel A (Bass)
  PCMSK0 |= (1<<PCINT0);                  // PB0 (PCINT0) overload at channel B (Middle)
  PCMSK0 |= (1<<PCINT4);                  // PB4 (PCINT4) overload at channel C (Treble)

  //ADCInit(ADC_REF_VCC);                 // just for testing purposes
  ADCInit(ADC_REF_EXT);                   // initialize AD converter, Uref = 4.096V
  //sei();                                // enable global interrupts - done in framework

  Serial.println(F("Program (13.04.2018) started:"));
	
  i = 0;
}

void loop() {
  // put your main code here, to run repeatedly:
  if (timerTemperature == 0) {            // 10 sec timeout ?
    timerTemperature = TIMER_TEMPERATURE;
    adc = ADCRead(6);                     // read temp sensor (0..100 deg celsius), 10mV per deg
                                          // at Uref 4.096V --> 4mV per digit --> divisor 2.5
    Serial.print(F("temp reading: "));
    Serial.print(adc);
    Serial.print(F(" -> "));
    Serial.print((uint16_t)((float)adc/2.5));
    Serial.println(F(" °C"));
    if (!(overload & (1<<7)) && (adc > 124))	{ // 0.5V/4.096V*1024
      overload |= (1<<7);                 // temp overload triggered at >50 deg
      Serial.println(F("thermal overload detected -> all channels off"));
    }
    else if ((overload & (1<<7)) && (adc < 100)) {	// 0.4V/4.096V*1024
      overload &= ~(1<<7);                // temp overload deleted at <40 deg
      Serial.println(F("thermal overload has ended"));
    }
  }
  if (overload & (1<<i)) {                // electr. overload on this channel ?
    valueNew = 0;                         // channel off
    if (!(overload & (1<<7))) PORTB |= (1<<PB2);  // LED permanently on if no overtemperature
    if (overloadMessage & (1<<i)) {       // message to be sent for this channel
      Serial.print(F("overload detected on channel "));
      Serial.println((char)('A'+i));
      overloadMessage &= ~(1<<i);	
    }
    if (timer[i] == 0) {                  // timer expired ?
      overload &= ~(1<<i);                // clear electr. overload for this channel
      Serial.print(F("overload might be gone on channel "));
      Serial.print((char)('A'+i));
      Serial.println(F(", we release it"));
    }
  }
  if (overload & (1<<7)) {                // thermal overload of system ?
    valueNew = 0;                         // channel off
    if (!timerBlink) {                    // thermal overload: LED at PB2 (D10) blinks (t=250ms)
      PORTB ^= (1<<PB2);
      timerBlink = 250;	
    }
  }
  if (!(overload & (1<<i)) && !(overload & (1<<7))) {
    // normal working condition, no overloads
    if (workingMode == 0) {			
      // read voltage level of each analog filter output on Filter-PCB
      adc = ADCRead(i);                   // ADCRead() returns 0...1023 (0...4.096V)
      // values for best visual impression obtained by practical tests
      static uint16_t lowLevel[NUM_CHANNELS] = {125,133,124};   // min level at which LEDs just switch off
      static uint16_t highLevel[NUM_CHANNELS] = {408,375,310};  // max level, at which LEDs are permanently on
      if (adc < lowLevel[i]) adc = lowLevel[i];
      if (adc > highLevel[i]) adc = highLevel[i];
      valueNew = map(adc,lowLevel[i],highLevel[i],0,255);       // new value 0..255 represents desired brightness
    }
    else if (workingMode == 1) {
      // switch to next channel when bass channel shows steep edge (rhythm mode)
      static int16_t adc0 = 0, adc1 = 0, adc2 = 0, adc3 = 0;
      _delay_ms(12);
      adc0 = adc1;
      adc1 = adc2;
      adc2 = adc3;
      adc3 = (uint16_t)ADCRead(0);        // read bass channel only
      if ((timerMode == 0) &&	
          (((adc2 > 0) && (adc3 > 0) && ((adc3 - adc2) > 107)) ||   // delta: 430mV
          ((adc1 > 0) && (adc3 > 0) && ((adc3 - adc1) > 125)) ||    // delta: 500mV
          ((adc0 > 0) && (adc3 > 0) && ((adc3 - adc0) > 144)))      // delta: 580mV
         ) {
        timerMode = 150;                  // next step in >=150ms at the earliest
        ii++;
        adc0 = adc1 = adc2 = 0;
      }
      // TEST TEST
      /*else {
        PORTB |= (1<<PB2);
        _delay_us(20);
        PORTB &= ~(1<<PB2);
      }*/
      if ((ii % NUM_CHANNELS) == i)
        valueNew = 255;
      else
        valueNew = 0;
    }
    else {  // cyclic mode
      if (timerMode == 0) {
        timerMode = 300;
        ii++;
      }
      if ((ii % NUM_CHANNELS) == i)
        valueNew = 255;
      else
        valueNew = 0;
    }
  }
	
  if (valueNew != valueOld[i]) {
    if (i != 2) {
      pwm = myExp[valueNew];            // translating PWM value to brightness (only for bass & middle frequ)
    }  
    else {
      pwm = valueNew;                   // no transaltion for treble (proved to be best solution visually)
    }  
    // write PWM value into register
    if (i == 0) {
      OCR0A = pwm;
    }  
    else if (i == 1) {
      OCR0B = pwm;
    }
    else {
      OCR2A = pwm;
    }  
    valueOld[i] = valueNew;
  }
	
  if (!overload) {                      // overload gone ?
    PORTB &= ~(1<<PB2);                 // overload LED at PB2 (D10) off
  }
	
  if (i == 0 && switchCheck()) {        // switch pressed ?
    workingMode =  (workingMode + 1) % NUM_WORKING_MODES;
    Serial.print(F("new working mode: "));
    Serial.println(workingMode);
  }

  i++;
  i %= NUM_CHANNELS;
}
